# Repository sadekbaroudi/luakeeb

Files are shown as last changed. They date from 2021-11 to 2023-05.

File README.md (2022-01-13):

# Pronunciation

Lua Keyboard (luakeeb)

This is a reversible 95mm x 138mm pcb with support for mx switches (no hotswap), per key led, rotary encoders, and exposes the SDA/SCL/GND/VCC lines in the form of the pimoroni trackball pins (meaning you can add that as well, though the case doesn't support it, so you'll need to devise your own mechanism). It also supports the adafruit qwiic connector, so you can add that connector and access I2C (the sda/scl pins) via a standard format!

See https://www.sparkfun.com/qwiic for details

Note that the 6th column can be broken off. The only thing you need to do is (if using per key leds) solder the jumper near the bottom outside of the board, near the mounting hole. You should solder the jumper on the bottom side of the board (if left half, bottom side of the left half, if right half, bottom side of the right half)

# Support me!

I have spent a lot of time and money designing prototypes, testing, developing, etc. Any contributions would be greatly appreciated!

If you don't want to, or can't afford to support me, please send me a message to let me know you've built one, along with pictures. Also, feel free to submit a pull request with pictures into this repository. I'd be happy to showcase your build.

Reddit: /u/sadekbaroudi
Discord: sadekbaroudi#1258



# Cases

## Split case

You can find the split cases here:
https://github.com/sadekbaroudi/luakeeb/tree/master/cases

I only included the left side, since you can use your slicing software to mirror it to 3d print the right side.

## Monoblock support

This keyboard has the exact same layout as the ffkb ( https://github.com/sadekbaroudi/ffkb )

It was designed in such a way that it is perfectly compatible with the ffkb case. The only considerations are:
* The usb port on ffkb is in the center. In this case, you have two (one for each half). You'll need to cut out a spot on each half to allow you to plug it in.
* The trrs jacks need cut outs as well. However, if you don't care about splitting them up, you can solder the halves together instead of using jacks. In the image below, just solder the outer pins to each other, as indicated by the arrows in the image below.

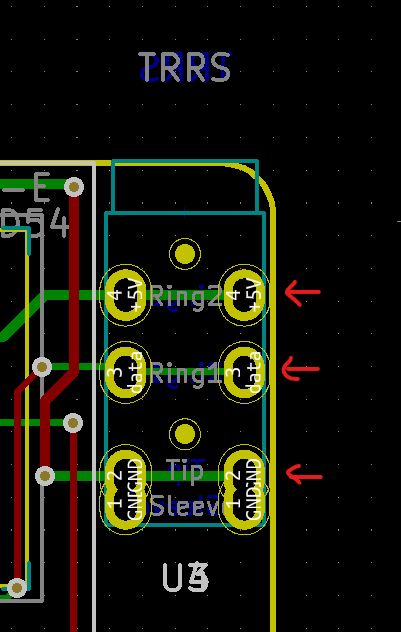
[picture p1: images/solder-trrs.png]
soldertrrs


# Firmware

The general folder for the firmware is here:
https://github.com/sadekbaroudi/qmk_firmware/tree/master/keyboards/fingerpunch/luakeeb/

# Pictures

build

pcbs

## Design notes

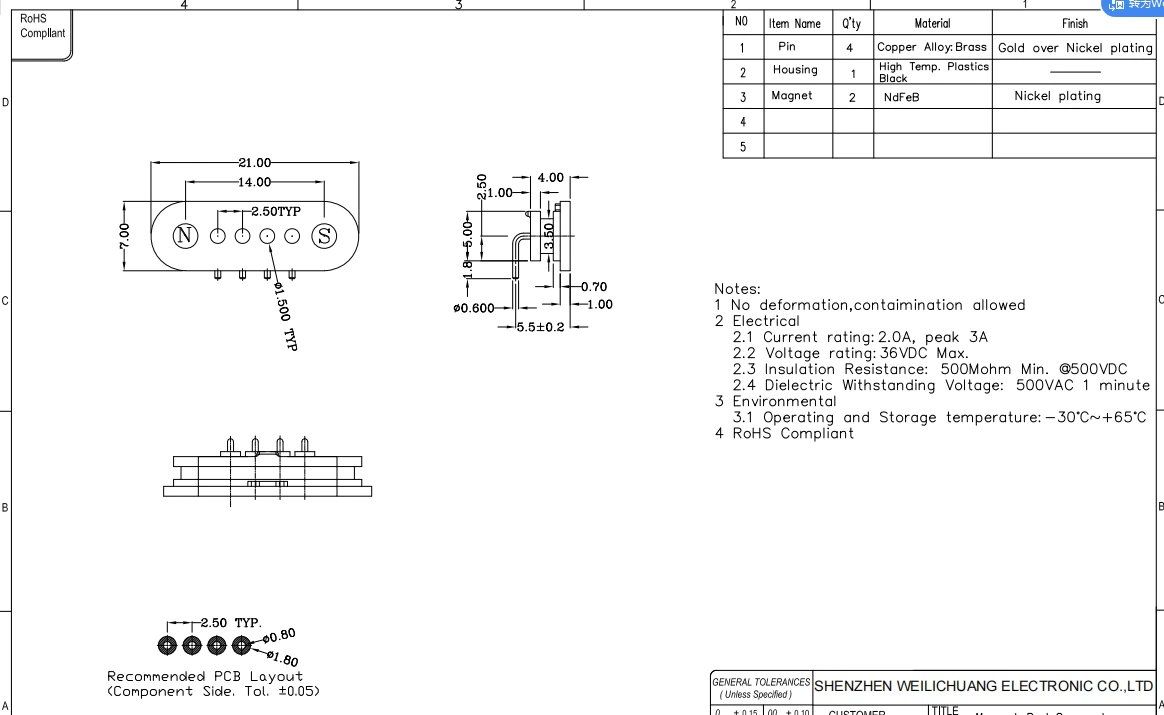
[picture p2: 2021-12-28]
datasheets/pogopins.webp

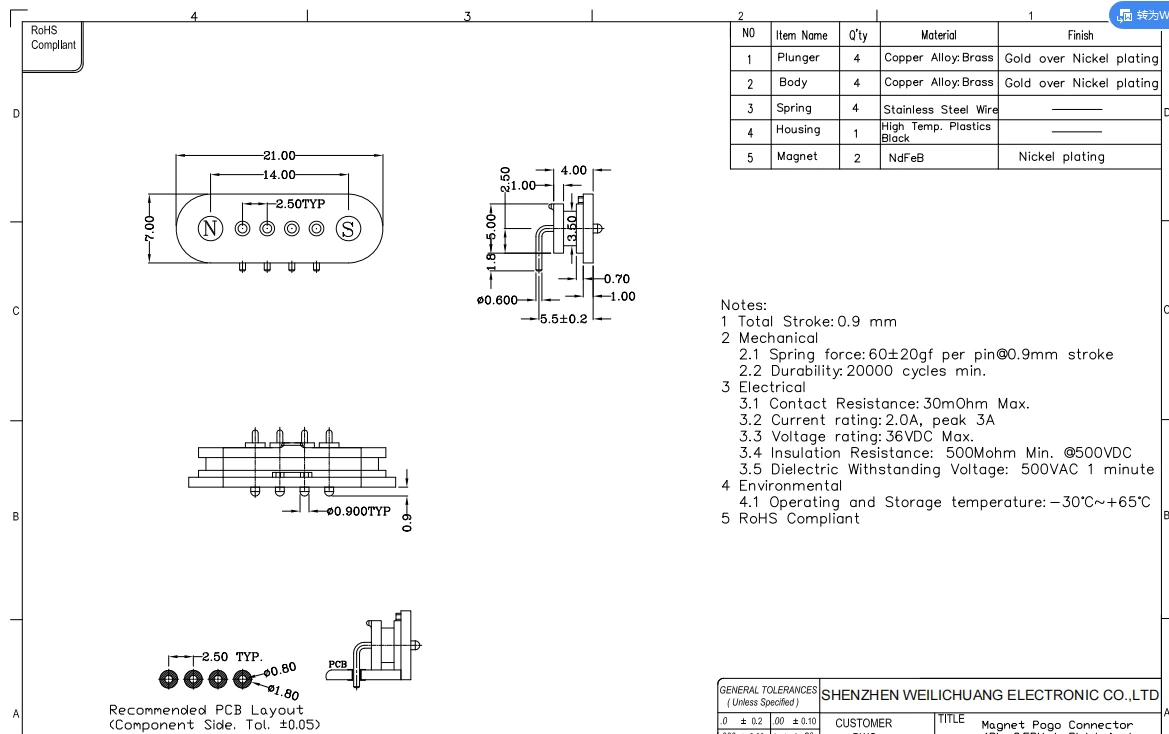
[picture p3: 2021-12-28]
datasheets/pogopins2.webp

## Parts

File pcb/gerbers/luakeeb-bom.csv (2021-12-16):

Comment | Designator | Footprint | LCSC
1N4148W | D1,D2,D3,D4,D5,D6,D7,D8,D9,D10,D11,D12,D13,D14,D15,D16,D17,D18,D19,D20,D21,D22,D23,D24,D25,D26,D27,D28,D29,D30,D31,D32,D33,D34,D35,D36,D37,D80,D81,D82,D83,D84,D85,D86 | Diode_SMD:D_SOD-123 | C727110
SK6812MINI-E | D38,D39,D40,D41,D42,D43,D44,D45,D46,D47,D48,D49,D50,D51,D52,D53,D54,D55,D56,D57,D58,D59,D60,D61,D62,D63,D64,D65,D66,D67,D68,D69,D70,D71,D72,D73,D74,D75,D76,D77,D78,D79 | kicad-keyboard-parts:MX_SK6812MINI-E
Pimoroni | J1 | other_parts:pimoroni
Conn_01x04_Female | J2,J3 | Connector_JST:JST_SH_BM04B-SRSS-TB_1x04-1MP_P1.00mm_Vertical
Conn_01x02_Female | J4,J5 | Connector_JST:JST_PH_S2B-PH-K_1x02_P2.00mm_Horizontal | C173752
Jumper_2_Open | JP1,JP2 | Jumper:SolderJumper-2_P1.3mm_Open_RoundedPad1.0x1.5mm
10k | R4 | Resistor_SMD:R_0805_2012Metric | C17414
SW_Push | SW1,SW2,SW3,SW4,SW5,SW6,SW9,SW10,SW11,SW12,SW13,SW14,SW15,SW16,SW21,SW22,SW23,SW24,SW25,SW34,SW35 | keyswitches:SW_MX_reversible_minimal
SW_DPDT_x2 | SW17 | Button_Switch_THT:SW_CuK_OS102011MA1QN1_SPDT_Angled | C226259
SW_Push | SW8,SW41 | random-keyboard-parts:SKQG-1155865
RotaryEncoder_Switch | SW7,SW42 | Keebio-Parts:RotaryEncoder_EC11-no-legs
ProMicro | U1 | Keebio-Parts:ArduinoProMicro
TRRS | U3,U4 | Keebio-Parts:TRRS-PJ-320A

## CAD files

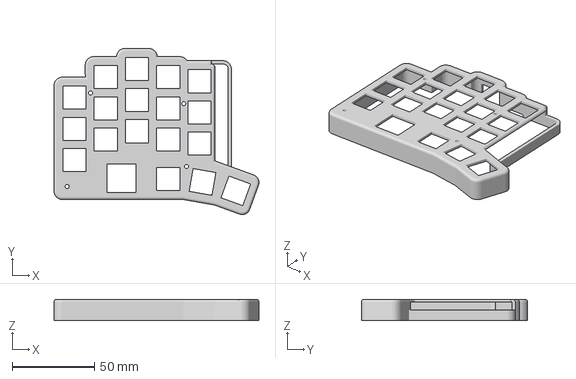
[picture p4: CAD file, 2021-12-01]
cases/5column/body.3mf
124.8 x 101.2 x 13.0 mm

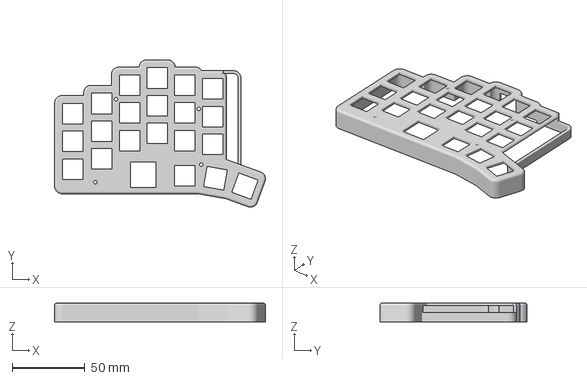
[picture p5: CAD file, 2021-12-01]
cases/6column/body.3mf
144.9 x 101.2 x 13.0 mm

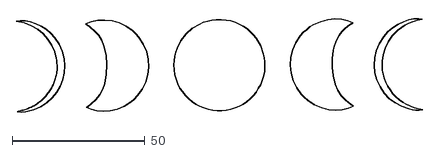
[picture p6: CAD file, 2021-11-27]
logo/moonphase2.dxf
153.2 x 36.7

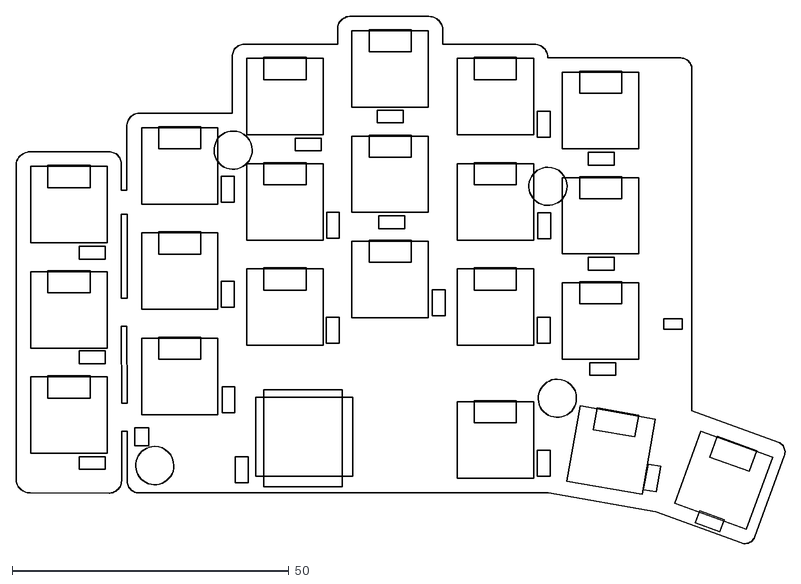
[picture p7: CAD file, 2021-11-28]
svgs/luakeeb-brd.dxf
138.9 x 95.2

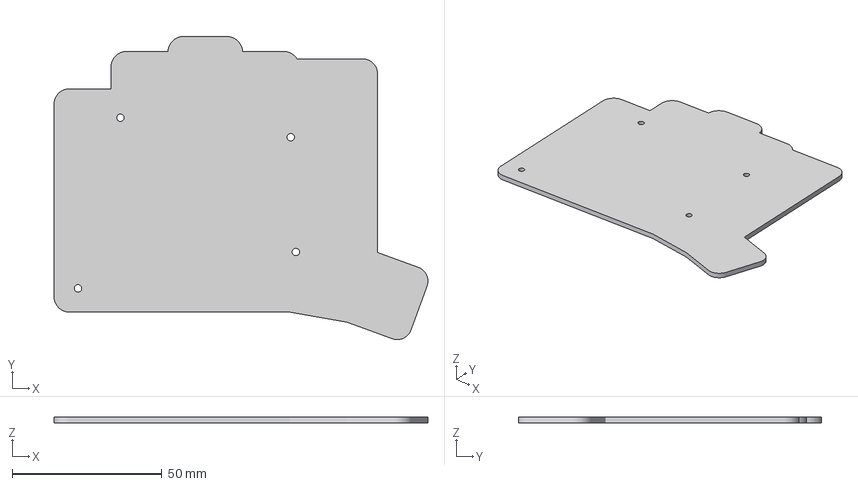
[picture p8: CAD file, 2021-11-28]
cases/5column/bottom-plate.3mf
124.8 x 101.2 x 2.00 mm

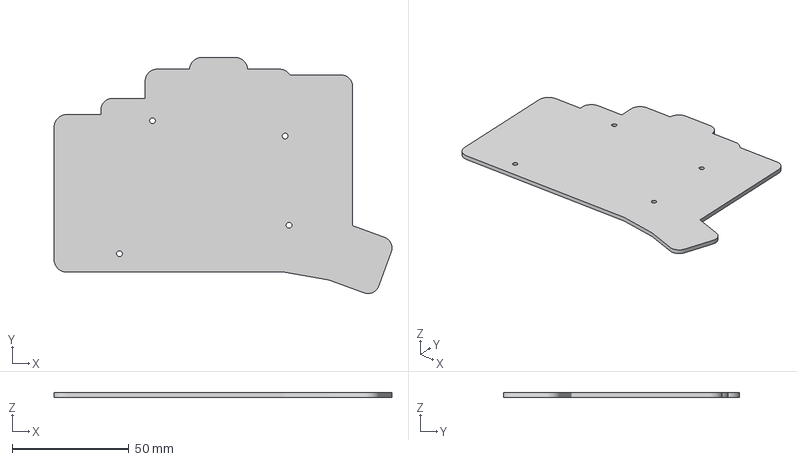
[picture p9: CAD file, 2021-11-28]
cases/6column/bottom-plate.3mf
144.9 x 101.2 x 2.00 mm

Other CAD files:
cases/5column/body.stl
cases/5column/bottom-plate.stl
cases/6column/body.stl
cases/6column/bottom-plate.stl

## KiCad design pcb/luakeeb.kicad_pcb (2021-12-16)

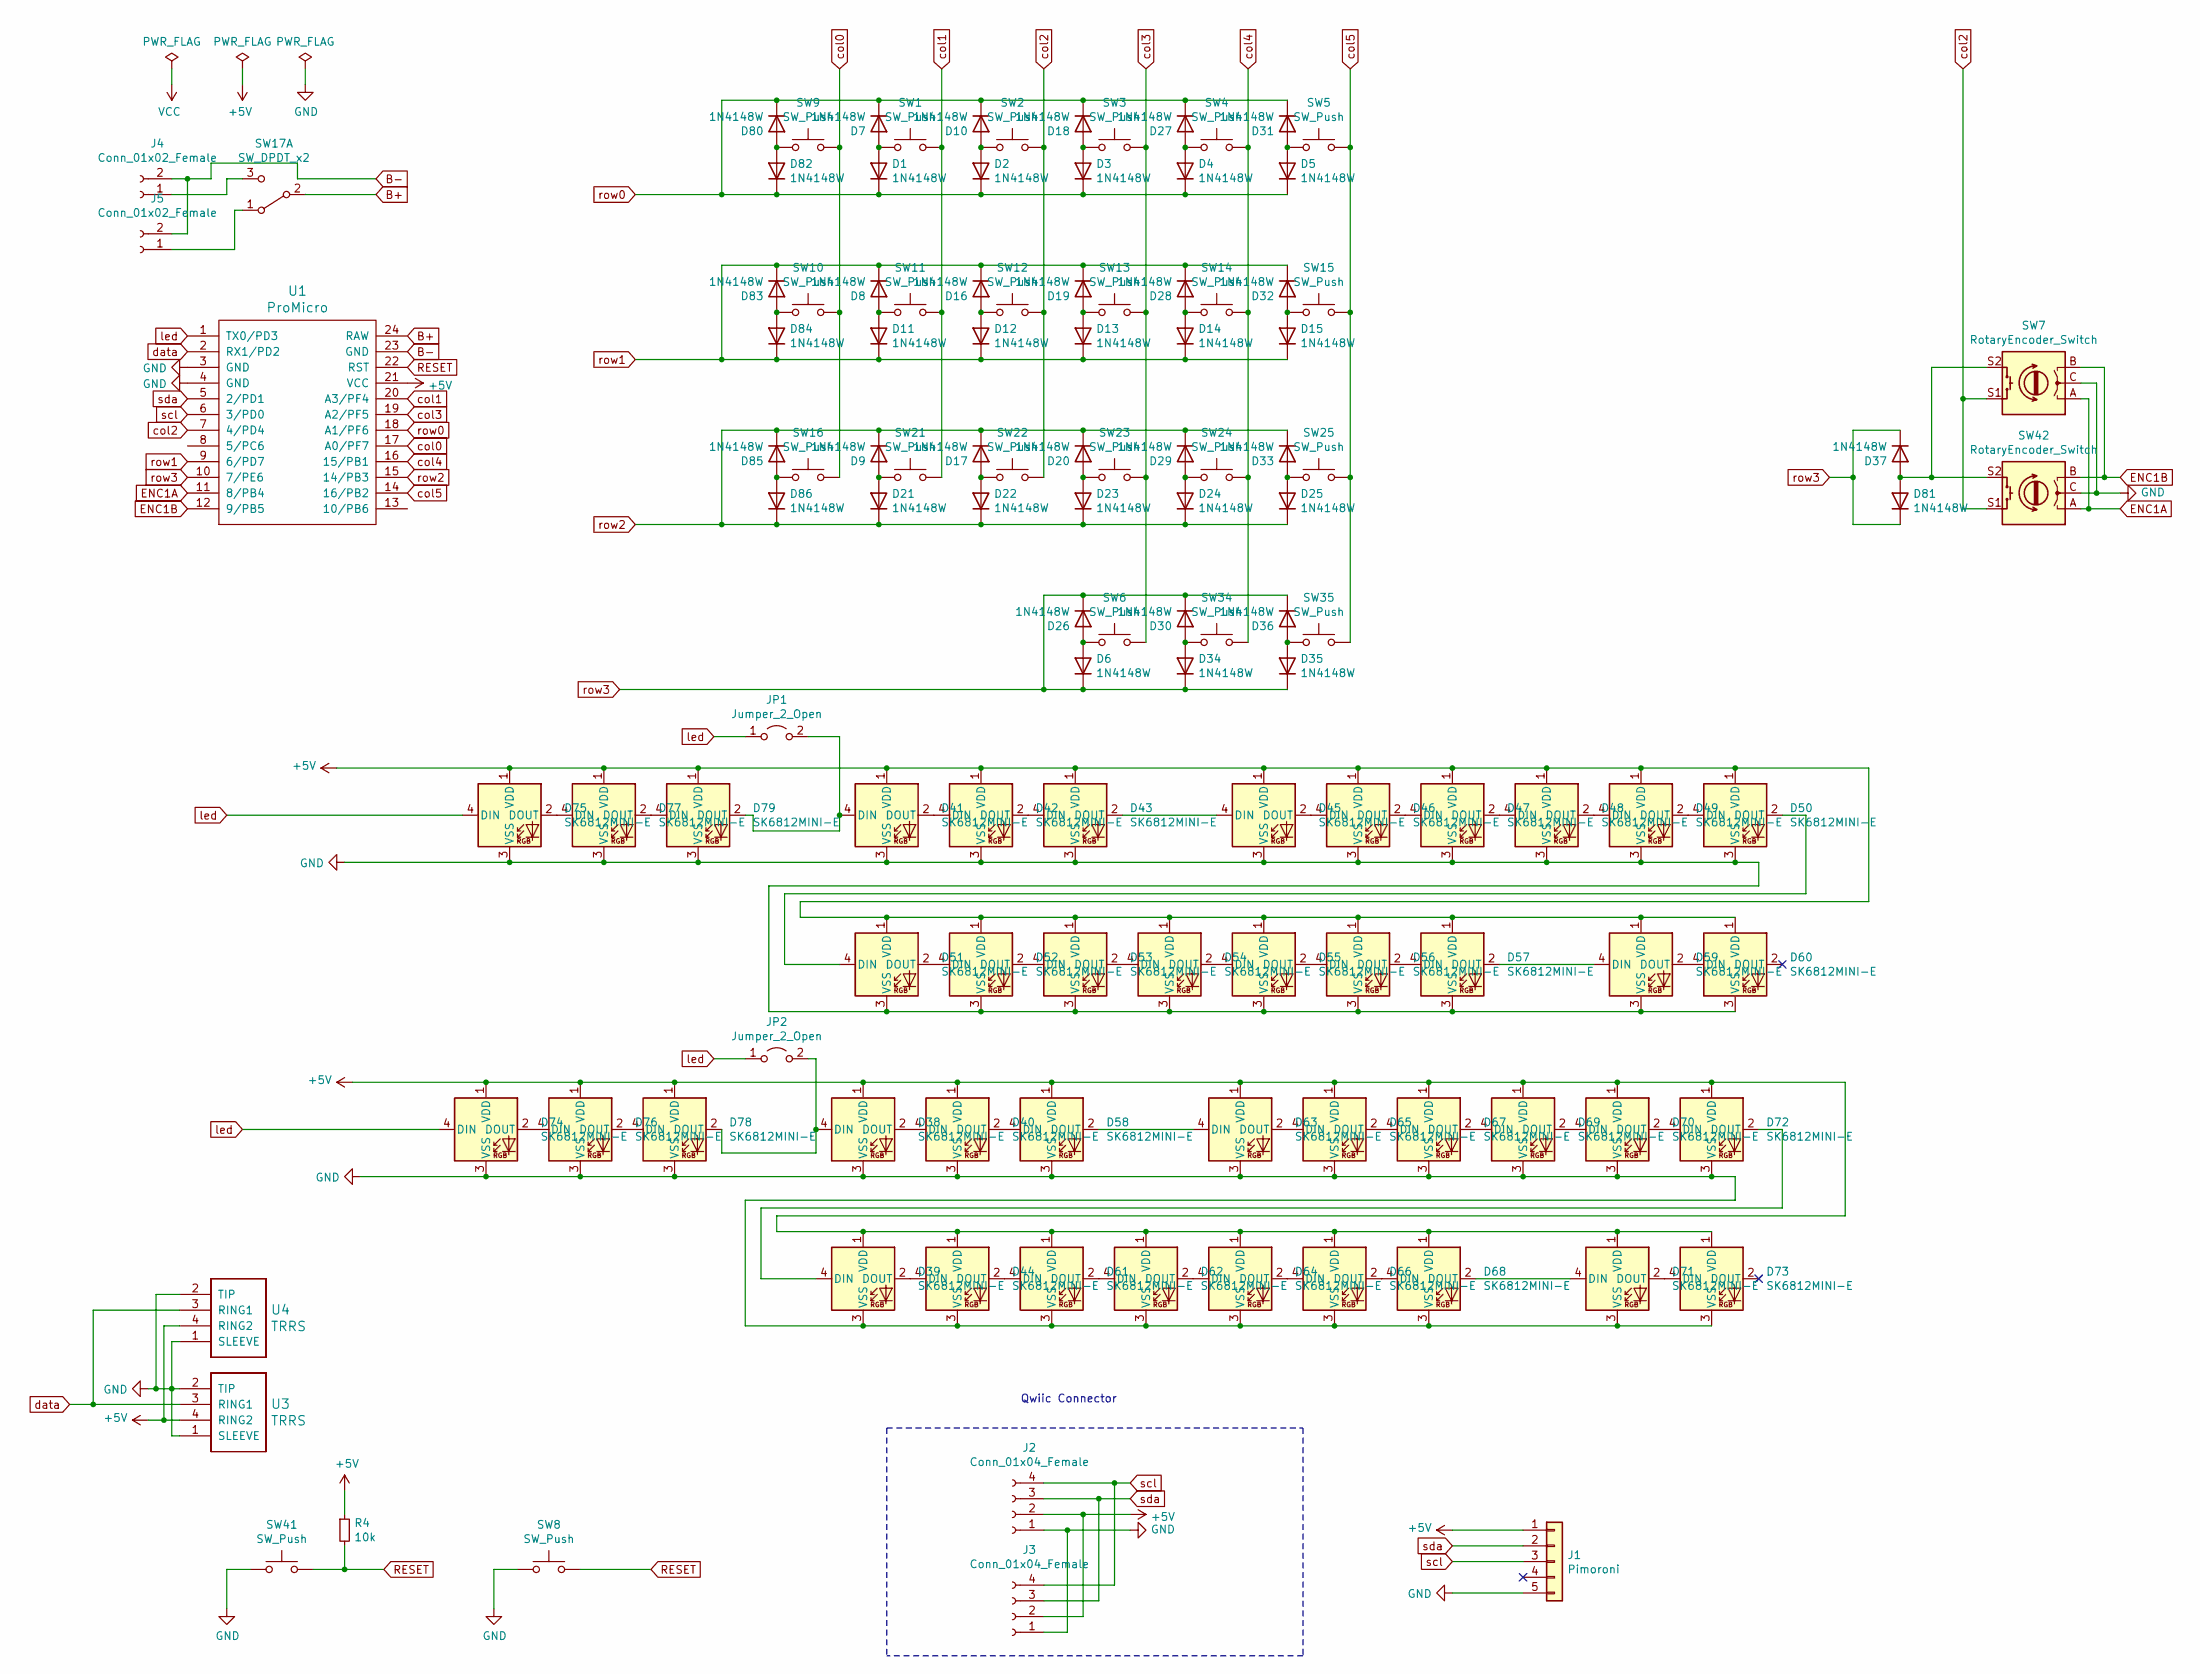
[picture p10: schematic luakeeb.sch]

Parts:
D1, D2, D3, D4, D5, D6, D7, D8, D9, D10, D11, D12, D13, D14, D15, D16, D17, D18, D19, D20, D21, D22, D23, D24, D25, D26, D27, D28, D29, D30, D31, D32, D33, D34, D35, D36, D37, D80, D81, D82, D83, D84, D85, D86: 1N4148W; D_SOD-123; LCSC C727110
D38, D39, D40, D41, D42, D43, D44, D45, D46, D47, D48, D49, D50, D51, D52, D53, D54, D55, D56, D57, D58, D59, D60, D61, D62, D63, D64, D65, D66, D67, D68, D69, D70, D71, D72, D73, D74, D75, D76, D77, D78, D79: SK6812MINI-E; MX_SK6812MINI-E
J1: Pimoroni; pimoroni
J2, J3: Conn_01x04_Female; JST_SH_BM04B-SRSS-TB_1x04-1MP_P1.00mm_Vertical
J4, J5: Conn_01x02_Female; JST_PH_S2B-PH-K_1x02_P2.00mm_Horizontal; LCSC C173752
JP1, JP2: Jumper_2_Open; SolderJumper-2_P1.3mm_Open_RoundedPad1.0x1.5mm
R4: 10k; R_0805_2012Metric; LCSC C17414
SW1, SW2, SW3, SW4, SW5, SW6, SW9, SW10, SW11, SW12, SW13, SW14, SW15, SW16, SW21, SW22, SW23, SW24, SW25, SW34, SW35: SW_Push; SW_MX_reversible_minimal
SW7, SW42: RotaryEncoder_Switch; RotaryEncoder_EC11-no-legs
SW8, SW41: SW_Push; SKQG-1155865
SW17: SW_DPDT_x2; SW_CuK_OS102011MA1QN1_SPDT_Angled; LCSC C226259
U1: ProMicro; ArduinoProMicro
U3, U4: TRRS; TRRS-PJ-320A

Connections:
+5V: D38.1 (VDD), D39.1 (VDD), D40.1 (VDD), D41.1 (VDD), D42.1 (VDD), D43.1 (VDD), D44.1 (VDD), D45.1 (VDD), D46.1 (VDD), D47.1 (VDD), D48.1 (VDD), D49.1 (VDD), D50.1 (VDD), D51.1 (VDD), D52.1 (VDD), D53.1 (VDD), D54.1 (VDD), D55.1 (VDD), D56.1 (VDD), D57.1 (VDD), D58.1 (VDD), D59.1 (VDD), D60.1 (VDD), D61.1 (VDD), D62.1 (VDD), D63.1 (VDD), D64.1 (VDD), D65.1 (VDD), D66.1 (VDD), D67.1 (VDD), D68.1 (VDD), D69.1 (VDD), D70.1 (VDD), D71.1 (VDD), D72.1 (VDD), D73.1 (VDD), D74.1 (VDD), D75.1 (VDD), D76.1 (VDD), D77.1 (VDD), D78.1 (VDD), D79.1 (VDD), J1.1, J2.2, J3.2, R4.1, U1.21 (VCC), U3.4 (RING2), U4.4 (RING2)
B+: SW17.2 (B), U1.24 (RAW)
B-: J4.2, J5.2, U1.23 (GND)
ENC1A: SW7.A, SW42.A, U1.11 (8/PB4)
ENC1B: SW7.B, SW42.B, U1.12 (9/PB5)
GND: D38.3 (VSS), D39.3 (VSS), D40.3 (VSS), D41.3 (VSS), D42.3 (VSS), D43.3 (VSS), D44.3 (VSS), D45.3 (VSS), D46.3 (VSS), D47.3 (VSS), D48.3 (VSS), D49.3 (VSS), D50.3 (VSS), D51.3 (VSS), D52.3 (VSS), D53.3 (VSS), D54.3 (VSS), D55.3 (VSS), D56.3 (VSS), D57.3 (VSS), D58.3 (VSS), D59.3 (VSS), D60.3 (VSS), D61.3 (VSS), D62.3 (VSS), D63.3 (VSS), D64.3 (VSS), D65.3 (VSS), D66.3 (VSS), D67.3 (VSS), D68.3 (VSS), D69.3 (VSS), D70.3 (VSS), D71.3 (VSS), D72.3 (VSS), D73.3 (VSS), D74.3 (VSS), D75.3 (VSS), D76.3 (VSS), D77.3 (VSS), D78.3 (VSS), D79.3 (VSS), J1.5, J2.1, J3.1, SW7.C, SW8.1, SW41.1, SW42.C, U1.3 (GND), U1.4 (GND), U3.1 (SLEEVE), U3.2 (TIP), U4.1 (SLEEVE), U4.2 (TIP)
unnamed: D1.2 (A), D7.2 (A), SW1.1
unnamed: D2.2 (A), D10.2 (A), SW2.1
unnamed: D8.2 (A), D11.2 (A), SW11.1
unnamed: D12.2 (A), D16.2 (A), SW12.1
unnamed: D13.2 (A), D19.2 (A), SW13.1
unnamed: D14.2 (A), D28.2 (A), SW14.1
unnamed: D15.2 (A), D32.2 (A), SW15.1
unnamed: D17.2 (A), D22.2 (A), SW22.1
unnamed: D3.2 (A), D18.2 (A), SW3.1
unnamed: D20.2 (A), D23.2 (A), SW23.1
unnamed: D9.2 (A), D21.2 (A), SW21.1
unnamed: D24.2 (A), D29.2 (A), SW24.1
unnamed: D25.2 (A), D33.2 (A), SW25.1
unnamed: D6.2 (A), D26.2 (A), SW6.1
unnamed: D4.2 (A), D27.2 (A), SW4.1
unnamed: D30.2 (A), D34.2 (A), SW34.1
unnamed: D5.2 (A), D31.2 (A), SW5.1
unnamed: D35.2 (A), D36.2 (A), SW35.1
unnamed: D37.2 (A), D81.2 (A), SW7.S2, SW42.S2
unnamed: D38.2 (DOUT), D40.4 (DIN)
unnamed: D38.4 (DIN), D78.2 (DOUT), JP2.2 (B)
unnamed: D39.2 (DOUT), D44.4 (DIN)
unnamed: D39.4 (DIN), D72.2 (DOUT)
unnamed: D40.2 (DOUT), D58.4 (DIN)
unnamed: D41.2 (DOUT), D42.4 (DIN)
unnamed: D41.4 (DIN), D79.2 (DOUT), JP1.2 (B)
unnamed: D42.2 (DOUT), D43.4 (DIN)
unnamed: D43.2 (DOUT), D45.4 (DIN)
unnamed: D44.2 (DOUT), D61.4 (DIN)
unnamed: D45.2 (DOUT), D46.4 (DIN)
unnamed: D46.2 (DOUT), D47.4 (DIN)
unnamed: D47.2 (DOUT), D48.4 (DIN)
unnamed: D48.2 (DOUT), D49.4 (DIN)
unnamed: D49.2 (DOUT), D50.4 (DIN)
unnamed: D50.2 (DOUT), D51.4 (DIN)
unnamed: D51.2 (DOUT), D52.4 (DIN)
unnamed: D52.2 (DOUT), D53.4 (DIN)
unnamed: D53.2 (DOUT), D54.4 (DIN)
unnamed: D54.2 (DOUT), D55.4 (DIN)
unnamed: D55.2 (DOUT), D56.4 (DIN)
unnamed: D56.2 (DOUT), D57.4 (DIN)
unnamed: D57.2 (DOUT), D59.4 (DIN)
unnamed: D58.2 (DOUT), D63.4 (DIN)
unnamed: D59.2 (DOUT), D60.4 (DIN)
unnamed: D61.2 (DOUT), D62.4 (DIN)
unnamed: D62.2 (DOUT), D64.4 (DIN)
unnamed: D63.2 (DOUT), D65.4 (DIN)
unnamed: D64.2 (DOUT), D66.4 (DIN)
unnamed: D65.2 (DOUT), D67.4 (DIN)
unnamed: D66.2 (DOUT), D68.4 (DIN)
unnamed: D67.2 (DOUT), D69.4 (DIN)
unnamed: D68.2 (DOUT), D71.4 (DIN)
unnamed: D69.2 (DOUT), D70.4 (DIN)
unnamed: D70.2 (DOUT), D72.4 (DIN)
unnamed: D71.2 (DOUT), D73.4 (DIN)
unnamed: D74.2 (DOUT), D76.4 (DIN)
unnamed: D75.2 (DOUT), D77.4 (DIN)
unnamed: D76.2 (DOUT), D78.4 (DIN)
unnamed: D77.2 (DOUT), D79.4 (DIN)
unnamed: D80.2 (A), D82.2 (A), SW9.1
unnamed: D83.2 (A), D84.2 (A), SW10.1
unnamed: D85.2 (A), D86.2 (A), SW16.1
unnamed: J4.1, SW17.3 (C)
unnamed: J5.1, SW17.1 (A)
RESET: R4.2, SW8.2, SW41.2, U1.22 (RST)
col0: SW9.2, SW10.2, SW16.2, U1.17 (A0/PF7)
col1: SW1.2, SW11.2, SW21.2, U1.20 (A3/PF4)
col2: SW2.2, SW7.S1, SW12.2, SW22.2, SW42.S1, U1.7 (4/PD4)
col3: SW3.2, SW6.2, SW13.2, SW23.2, U1.19 (A2/PF5)
col4: SW4.2, SW14.2, SW24.2, SW34.2, U1.16 (15/PB1)
col5: SW5.2, SW15.2, SW25.2, SW35.2, U1.14 (16/PB2)
data: U1.2 (RX1/PD2), U3.3 (RING1), U4.3 (RING1)
led: D74.4 (DIN), D75.4 (DIN), JP1.1 (A), JP2.1 (A), U1.1 (TX0/PD3)
row0: D1.1 (K), D2.1 (K), D3.1 (K), D4.1 (K), D5.1 (K), D7.1 (K), D10.1 (K), D18.1 (K), D27.1 (K), D31.1 (K), D80.1 (K), D82.1 (K), U1.18 (A1/PF6)
row1: D8.1 (K), D11.1 (K), D12.1 (K), D13.1 (K), D14.1 (K), D15.1 (K), D16.1 (K), D19.1 (K), D28.1 (K), D32.1 (K), D83.1 (K), D84.1 (K), U1.9 (6/PD7)
row2: D9.1 (K), D17.1 (K), D20.1 (K), D21.1 (K), D22.1 (K), D23.1 (K), D24.1 (K), D25.1 (K), D29.1 (K), D33.1 (K), D85.1 (K), D86.1 (K), U1.15 (14/PB3)
row3: D6.1 (K), D26.1 (K), D30.1 (K), D34.1 (K), D35.1 (K), D36.1 (K), D37.1 (K), D81.1 (K), U1.10 (7/PE6)
scl: J1.3, J2.4, J3.4, U1.6 (3/PD0)
sda: J1.2, J2.3, J3.3, U1.5 (2/PD1)

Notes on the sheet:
Qwiic Connector

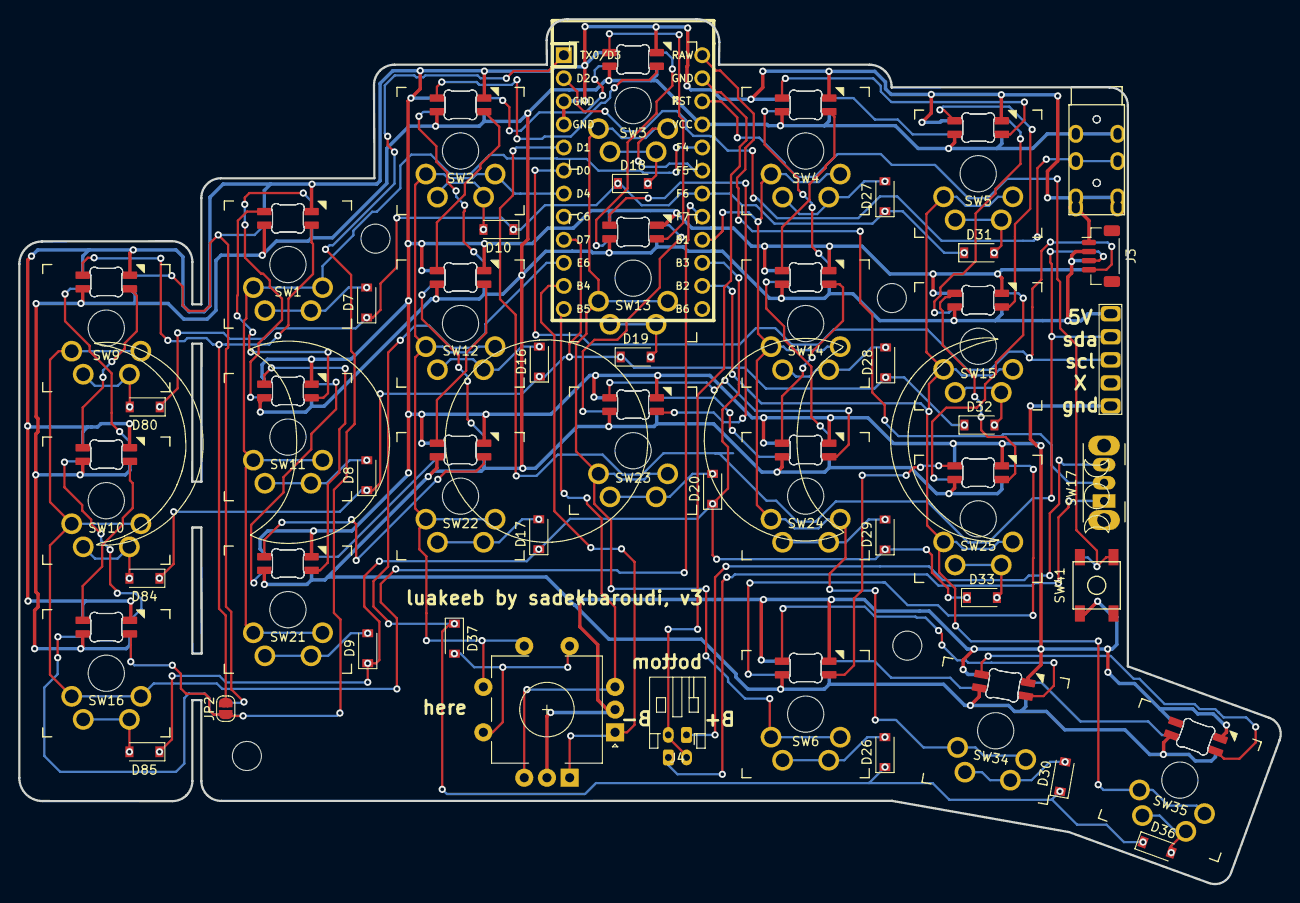
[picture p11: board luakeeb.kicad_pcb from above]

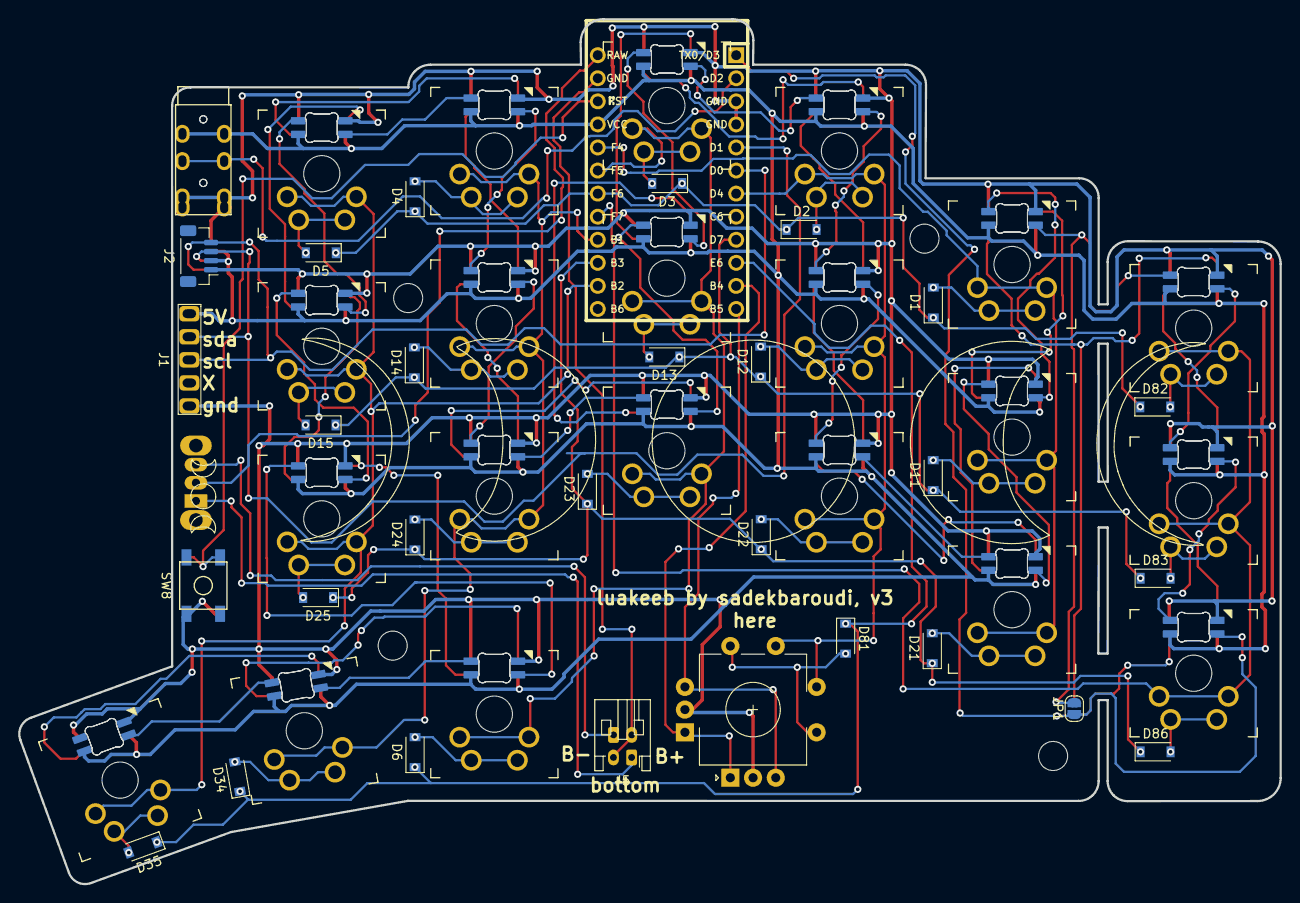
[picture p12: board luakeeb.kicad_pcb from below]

Board: 2 copper layers, 138.9 x 95.2 mm, 122 parts (50 on the bottom side), 85 nets.

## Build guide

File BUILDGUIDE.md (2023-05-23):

# Parts

For this pcb, here are the components you will need:

| Component | Quantity | Link |
| --- | --- | --- |
| MCU (Pro Micro compatible, Elite-c compatible, or nice!nano compatible | 2 | Google it, they're everywhere |
| SMD Diodes 0805 | 44 | https://www.lcsc.com/product-detail/Switching-Diode_TWGMC-1N4148W_C727110.html |
| SMD 10k resistor (optional, you can solder the pads together) | 2 | https://www.lcsc.com/product-detail/Chip-Resistor-Surface-Mount_UNI-ROYAL-Uniroyal-Elec-0805W8F1002T5E_C17414.html |
| M2 10mm standoffs | 8 | https://keeb.io/products/m2-screws-and-standoffs?variant=47432051590 |
| M2 4-5mm screws | 16 | https://www.amazon.com/uxcell-0-4mm-Stainless-Socket-DIN912/dp/B01M5DVE9R |
| Reset switch | 2 | https://www.digikey.com/en/products/detail/c&k/PTS526%2520SM15%2520SMTR2%2520LFS/10056633 |
| TRRS jack | 2 | https://keeb.io/collections/diy-parts/products/trrs-jack-3-5mm |
| TRRS cable | 1 | https://www.amazon.com/3-5MM-Right-Stereo-Silver-Plating-Copper/dp/B07G36MZ1P |
| SK6812 mini-e LED (optional) | 42 | https://www.adafruit.com/product/4960 |
| EC11 Rotary encoder (optional) | 2 | https://www.adafruit.com/product/377 |
| Pimoroni trackball (optional) | 1 | https://shop.pimoroni.com/products/trackball-breakout |

# Case

You will need to have the case before you solder, since the switches are soldered to the pcb.

https://github.com/sadekbaroudi/luakeeb/tree/master/cases

Print the left case and bottom plate. You can use your slicing software to do horizontal mirroring to print the right case and plate.

## Updated cases

I have moved my cases and instructions here:
https://github.com/sadekbaroudi/fingerpunch/tree/master/keyboards/luakeeb/cases

# Building

As mentioned in the README.md, if you break off the 6th column, remember to solder the jumper on the bottom side of the board. You only need to do this if using per key LEDs. This reroutes the LED signal appropriately.

Building these is very straight forward. Solder all the components per the footprints on the board, in the following order:

Top side:
* Resistor (if you didn't get one, just solder the resistor pads together, they are located just above the reset switch)
* Reset switch
* Aux jack

Bottom side:
* Diodes
* Per key leds
* Headers or socket for the Pro micro compatible MCU (recommend you do this before the switches, so you can solder the headers from the top of the pcb)
* Switches (note that you'll need the case ready to go at this point, since the switches need to already be in the case when you solder them to the pcb)
* Pro micro (the pro micro should go in the correct direction, please be careful about this, as it's easy to put it in backwards)

Note: Once you solder the pro micro, you can no longer access the solder points below it. So make sure everything is done before you do this

Also, If you add rotary encoders, there are some nice covers you can 3d print and put on top for a cleaner look. This is optional, but recommended as it looks much better. See the stls directly in this folder:
* https://github.com/sadekbaroudi/bgkeeb/tree/master/cases/covers

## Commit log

2021-11-27 Lua Keeb initial commit
    [luakeeb-B_Cu.gbr, luakeeb-B_Mask.gbr, luakeeb-B_Paste.gbr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]
2021-11-28 added logo svgs and case stls and 3mf files
    [body.3mf, body.stl, bottom-plate.3mf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]
2021-11-28 added usb port hole to cases
    [body.3mf, body.stl]
2021-12-01 moved encoder a tiny bit to the right, to now match ffkb exactly
    [body.3mf, body.stl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]
2021-12-02 removed the need for separate firmware per half by updating the footprint for the MX switch
    [luakeeb-B_Cu.gbr, luakeeb-B_Mask.gbr, luakeeb-B_Paste.gbr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]
2021-12-10 I actually don't know what changed, I must have forgotten to commit, whoops
    [luakeeb-B_Cu.gbr, luakeeb-B_Mask.gbr, luakeeb-B_Paste.gbr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]
2021-12-10 added plates for the luakeeb
    [5col-bottomplate-B_Cu.gbr, 5col-bottomplate-B_Mask.gbr, 5col-bottomplate-B_Paste.gbr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]
2021-12-13 added support for the adafruit qwiic connector
    [luakeeb-B_Cu.gbr, luakeeb-B_Mask.gbr, luakeeb-B_Paste.gbr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]
2021-12-16 added wireless support for nice nano with wiring, jst connector, and on off switch
    [luakeeb-B_Cu.gbr, luakeeb-B_Mask.gbr, luakeeb-B_Paste.gbr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]
2021-12-16 forgot to add the gerber zips for some of the plates
2021-12-28 will use these pogo pin connectors
2022-01-13 updated firmware link to fingerpunch
